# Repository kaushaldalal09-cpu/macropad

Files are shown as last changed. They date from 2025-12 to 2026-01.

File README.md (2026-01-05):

# macropad

This macropad will serve three purposes. One is to increase efficiency for my work by opening my most used apps with the click of a button. The second purpose is for playing video games. And the third feature I want is to have a built in game of tetris using the keys and oled display. My macro pad will include a knob (which will increase/decrease the volume) , a oled screen (to show the volume, or the tetris game depending on what mode I'm in), 12 keys, and RGB lights. 

All silkscreen artwork was created by me

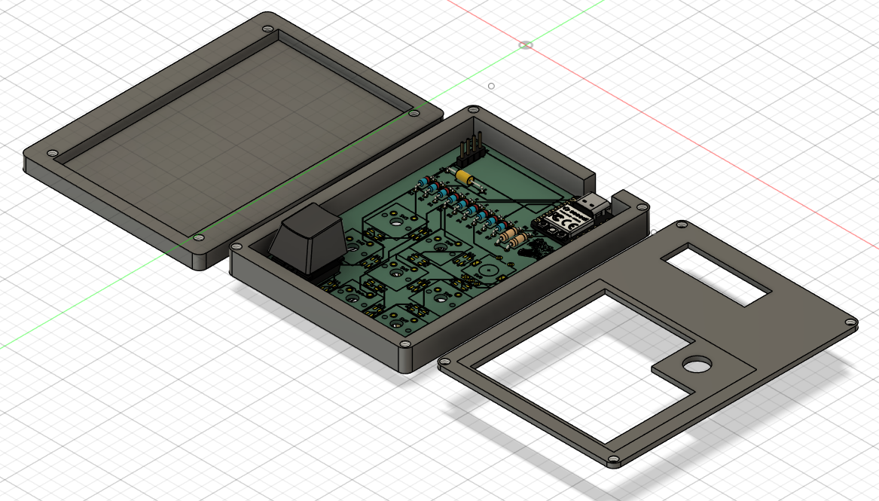
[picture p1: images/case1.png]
Overall hackpad

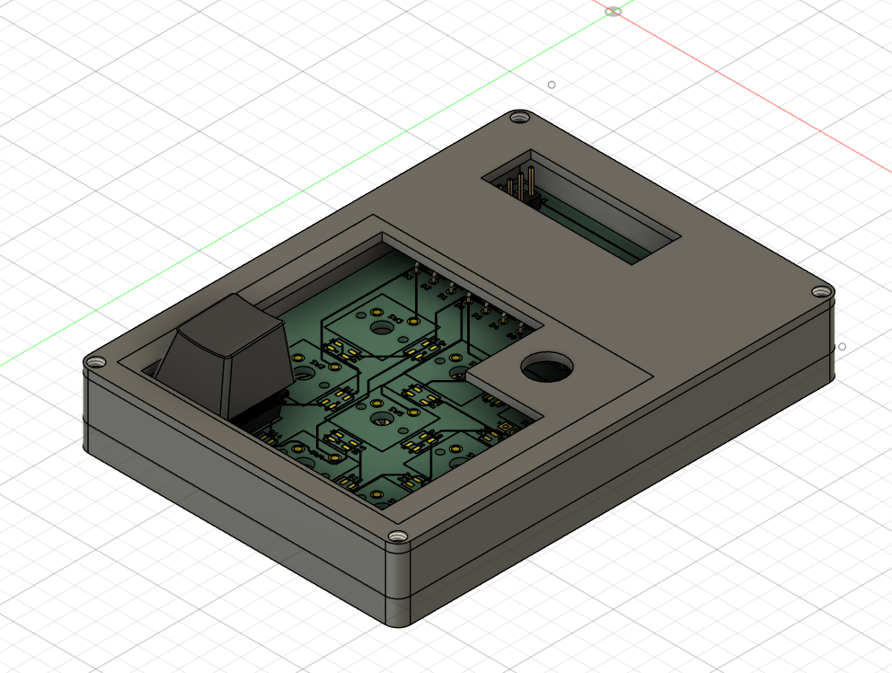
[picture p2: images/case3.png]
Fit together

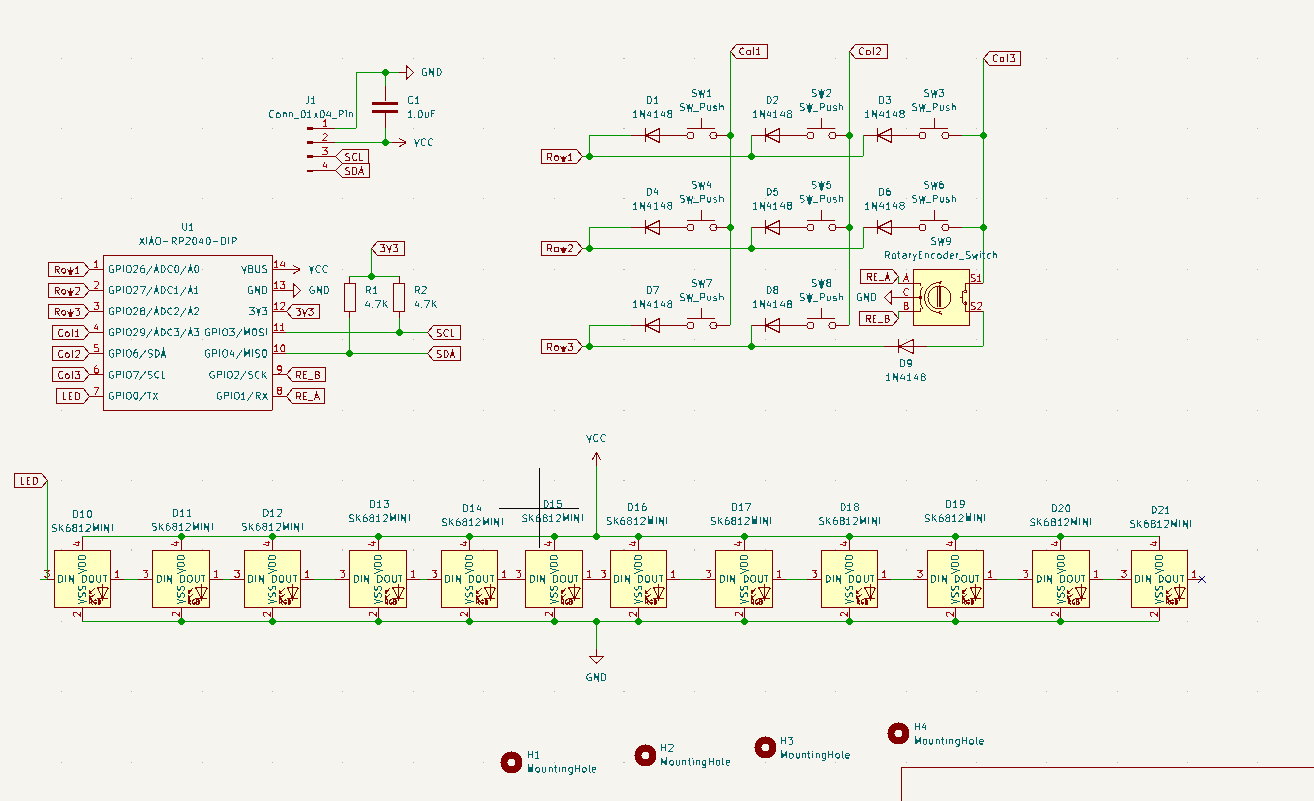
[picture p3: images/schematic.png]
Schematic

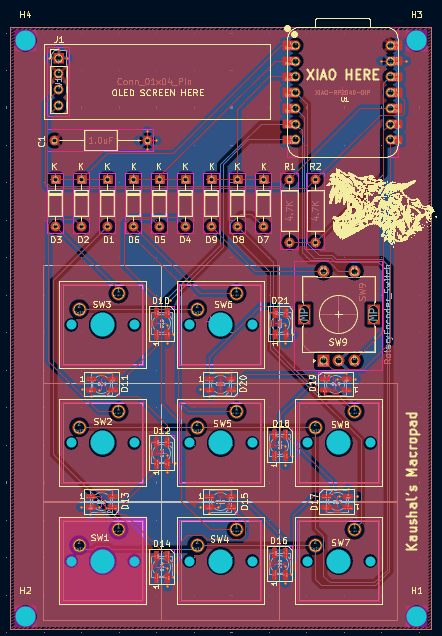
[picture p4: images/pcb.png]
PCB

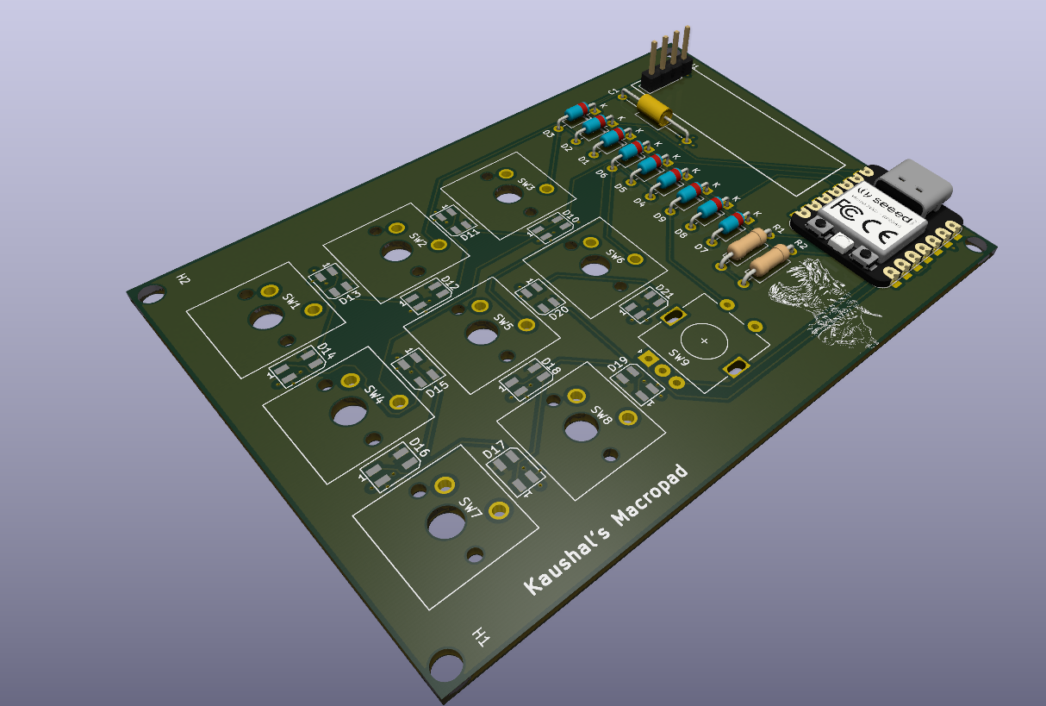
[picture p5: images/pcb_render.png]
PCB Render


BOM:
|Reference |Qty|Value |DNP|Exclude from BOM |Exclude from Board|Footprint |Datasheet |
|---|---|---|---|---|---|---|---|
|C1 |1  |1.0uF | | | |Capacitor_THT:C_Axial_L5.1mm_D3.1mm_P15.00mm_Horizontal |~ |
|D1,D2,D3,D4,D5,D6,D7,D8,D9 |9  |1N4148 | | | |Diode_THT:D_DO-35_SOD27_P7.62mm_Horizontal |https://assets.nexperia.com/documents/data-sheet/1N4148_1N4448.pdf |
|D10,D11,D12,D13,D14,D15,D16,D17,D18,D19,D20,D21|12 |SK6812MINI | | | |LED_SMD:LED_SK6812MINI_PLCC4_3.5x3.5mm_P1.75mm |https://cdn-shop.adafruit.com/product-files/2686/SK6812MINI_REV.01-1-2.pdf|
|H1,H2,H3,H4 |4  |MountingHole | |Excluded from BOM| |MountingHole:MountingHole_3.2mm_M3 |~ |
|J1 |1  |Conn_01x04_Pin | | | |Connector_PinHeader_2.54mm:PinHeader_1x04_P2.54mm_Vertical |~ |
|R1,R2 |2  |4.7K | | | |Resistor_THT:R_Axial_DIN0207_L6.3mm_D2.5mm_P10.16mm_Horizontal|~ |
|SW1,SW2,SW3,SW4,SW5,SW6,SW7,SW8 |8  |SW_Push | | | |Button_Switch_Keyboard:SW_Cherry_MX_1.00u_PCB |~ |
|SW9 |1  |RotaryEncoder_Switch| | | |Rotary_Encoder:RotaryEncoder_Alps_EC11E-Switch_Vertical_H20mm |~ |
|U1 |1  |XIAO-RP2040-DIP | | | |OPL Lib:XIAO-RP2040-DIP | |

Resources used:

https://www.thingiverse.com/thing:6940808

https://github.com/ConstantinoSchillebeeckx/cherry-mx-switch/blob/master/switch.step

https://github.com/ConstantinoSchillebeeckx/cherry-mx-keycaps/blob/master/STEP/Cherry%20MX%20keycaps.step

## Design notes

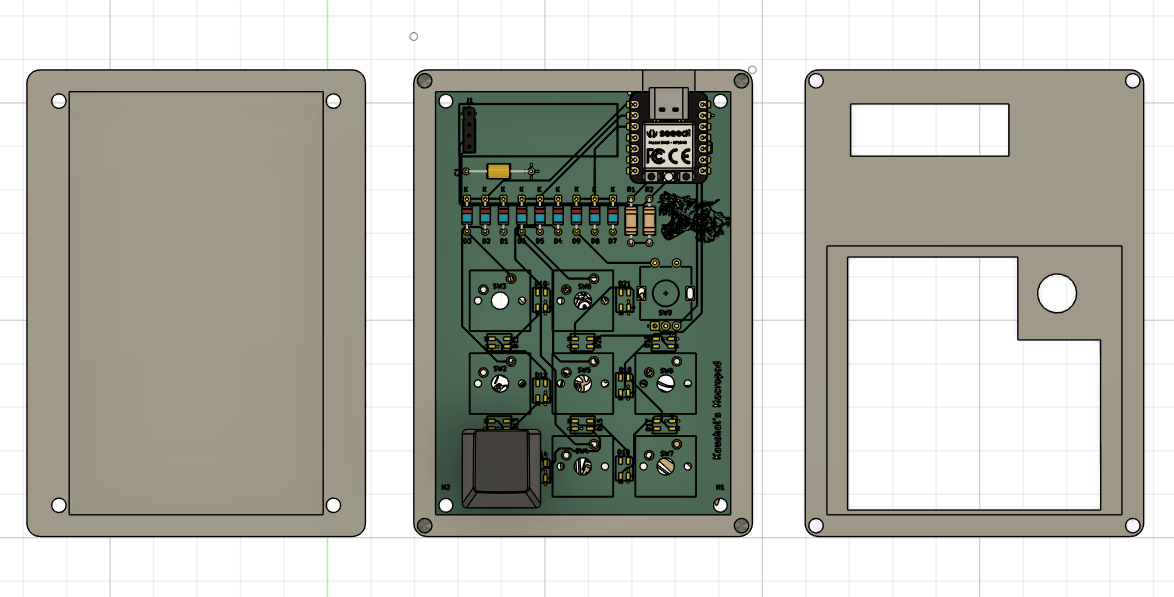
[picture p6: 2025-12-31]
images/case2.png

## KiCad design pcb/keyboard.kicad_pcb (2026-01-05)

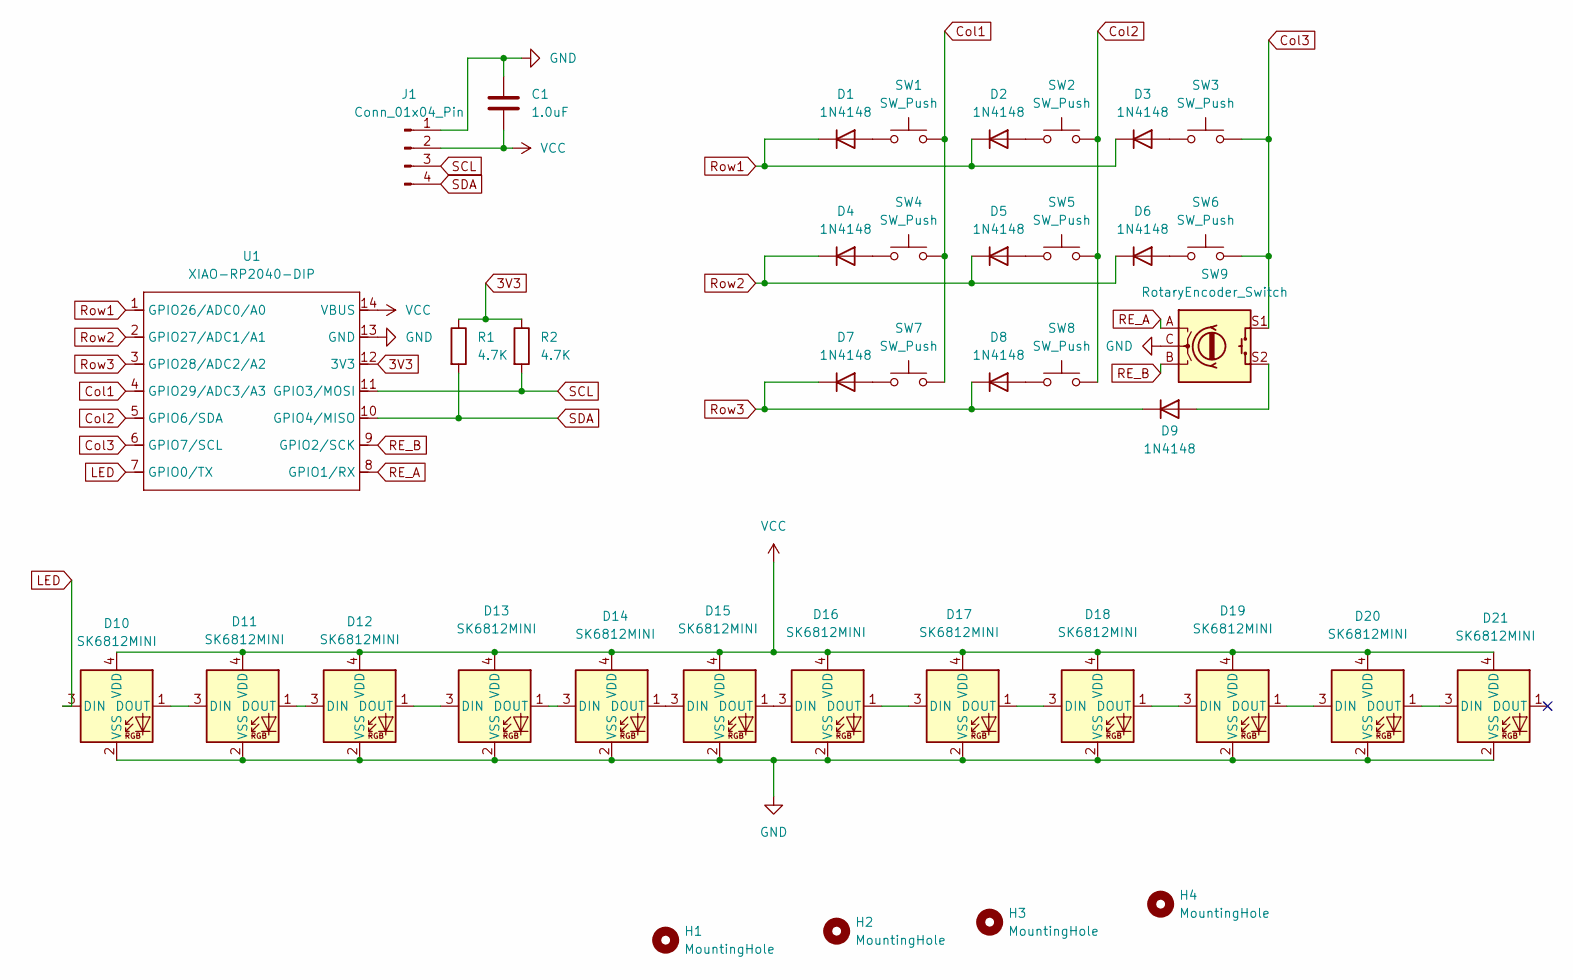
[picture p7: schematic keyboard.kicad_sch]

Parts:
C1: 1.0uF; C_Axial_L5.1mm_D3.1mm_P15.00mm_Horizontal
D1, D2, D3, D4, D5, D6, D7, D8, D9: 1N4148; D_DO-35_SOD27_P7.62mm_Horizontal
D10, D11, D12, D13, D14, D15, D16, D17, D18, D19, D20, D21: SK6812MINI; LED_SK6812MINI_PLCC4_3.5x3.5mm_P1.75mm
H1, H2, H3, H4: MountingHole; MountingHole_3.2mm_M3
J1: Conn_01x04_Pin; PinHeader_1x04_P2.54mm_Vertical
R1, R2: 4.7K; R_Axial_DIN0207_L6.3mm_D2.5mm_P10.16mm_Horizontal
SW1, SW2, SW3, SW4, SW5, SW6, SW7, SW8: SW_Push; SW_Cherry_MX_1.00u_PCB
SW9: RotaryEncoder_Switch; RotaryEncoder_Alps_EC11E-Switch_Vertical_H20mm
U1: XIAO-RP2040-DIP

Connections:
3V3: R1.1, R2.1, U1.12 (3V3)
Col1: SW1.2, SW4.2, SW7.2, U1.4 (GPIO29/ADC3/A3)
Col2: SW2.2, SW5.2, SW8.2, U1.5 (GPIO6/SDA)
Col3: SW3.2, SW6.2, SW9.S1, U1.6 (GPIO7/SCL)
GND: C1.1, D10.2 (VSS), D11.2 (VSS), D12.2 (VSS), D13.2 (VSS), D14.2 (VSS), D15.2 (VSS), D16.2 (VSS), D17.2 (VSS), D18.2 (VSS), D19.2 (VSS), D20.2 (VSS), D21.2 (VSS), J1.1, SW9.C, U1.13 (GND)
LED: D10.3 (DIN), U1.7 (GPIO0/TX)
unnamed: D1.2 (A), SW1.1
unnamed: D2.2 (A), SW2.1
unnamed: D3.2 (A), SW3.1
unnamed: D4.2 (A), SW4.1
unnamed: D5.2 (A), SW5.1
unnamed: D6.2 (A), SW6.1
unnamed: D7.2 (A), SW7.1
unnamed: D8.2 (A), SW8.1
unnamed: D9.2 (A), SW9.S2
unnamed: D10.1 (DOUT), D11.3 (DIN)
unnamed: D11.1 (DOUT), D12.3 (DIN)
unnamed: D12.1 (DOUT), D13.3 (DIN)
unnamed: D13.1 (DOUT), D14.3 (DIN)
unnamed: D14.1 (DOUT), D15.3 (DIN)
unnamed: D15.1 (DOUT), D16.3 (DIN)
unnamed: D16.1 (DOUT), D17.3 (DIN)
unnamed: D17.1 (DOUT), D18.3 (DIN)
unnamed: D18.1 (DOUT), D19.3 (DIN)
unnamed: D19.1 (DOUT), D20.3 (DIN)
unnamed: D20.1 (DOUT), D21.3 (DIN)
RE_A: SW9.A, U1.8 (GPIO1/RX)
RE_B: SW9.B, U1.9 (GPIO2/SCK)
Row1: D1.1 (K), D2.1 (K), D3.1 (K), U1.1 (GPIO26/ADC0/A0)
Row2: D4.1 (K), D5.1 (K), D6.1 (K), U1.2 (GPIO27/ADC1/A1)
Row3: D7.1 (K), D8.1 (K), D9.1 (K), U1.3 (GPIO28/ADC2/A2)
SCL: J1.3, R2.2, U1.11 (GPIO3/MOSI)
SDA: J1.4, R1.2, U1.10 (GPIO4/MISO)
VCC: C1.2, D10.4 (VDD), D11.4 (VDD), D12.4 (VDD), D13.4 (VDD), D14.4 (VDD), D15.4 (VDD), D16.4 (VDD), D17.4 (VDD), D18.4 (VDD), D19.4 (VDD), D20.4 (VDD), D21.4 (VDD), J1.2, U1.14 (VBUS)

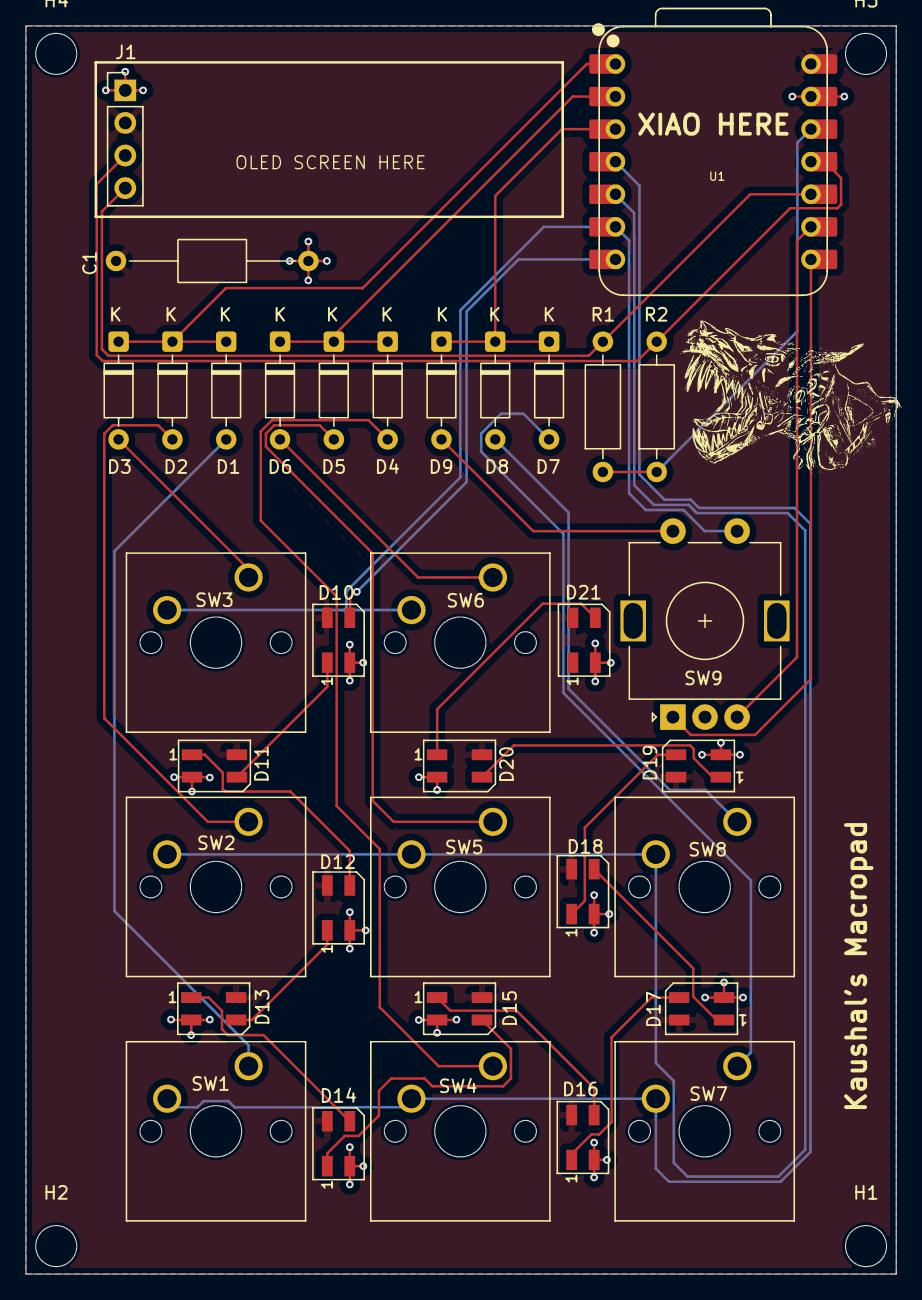
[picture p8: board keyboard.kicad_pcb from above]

Board: 2 copper layers, 67.9 x 97.3 mm, 39 parts (0 on the bottom side), 34 nets.

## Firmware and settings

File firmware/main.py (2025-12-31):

import board
import busio
import displayio
import terminalio
import random
import time
import adafruit_displayio_ssd1306
from adafruit_display_text import label
from kmk.kmk_keyboard import KMKKeyboard
from kmk.keys import KC
from kmk.scanners import DiodeOrientation
from kmk.modules.layers import Layers
from kmk.modules.encoder import EncoderHandler
from kmk.extensions.RGB import RGB

keyboard = KMKKeyboard()

# --- Hardware Configuration ---
keyboard.col_pins = (board.GP29, board.GP6, board.GP7)
keyboard.row_pins = (board.GP26, board.GP27, board.GP28)
keyboard.diode_orientation = DiodeOrientation.COL2ROW

# RGB Setup on GPIO0 (Pin 7)
rgb = RGB(pixel_pin=board.GP0, num_pixels=1, val_limit=255, hue_default=0)
keyboard.extensions.append(rgb)

# Encoder and Layer Modules
layers = Layers()
encoder_handler = EncoderHandler()
keyboard.modules = [layers, encoder_handler]
encoder_handler.pins = ((board.GP1, board.GP2, None, False),)

# OLED Initialization (SCL: GP3, SDA: GP4)
displayio.release_displays()
i2c = busio.I2C(scl=board.GP3, sda=board.GP4)
display_bus = displayio.I2CDisplay(i2c, device_address=0x3C)
display = adafruit_displayio_ssd1306.SSD1306(display_bus, width=128, height=32)

# --- Tetris Engine Constants ---
BOARD_W = 10
BOARD_H = 8
SHAPES = [
    [[1, 1, 1, 1]], # I
    [[1, 1], [1, 1]], # O
    [[0, 1, 0], [1, 1, 1]], # T
    [[0, 1, 1], [1, 1, 0]], # S
    [[1, 1, 0], [0, 1, 1]], # Z
    [[1, 0, 0], [1, 1, 1]], # L
    [[0, 0, 1], [1, 1, 1]]  # J
]

class TetrisGame:
    def __init__(self):
        self.reset()

    def reset(self):
        self.board = [[0] * BOARD_W for _ in range(BOARD_H)]
        self.new_piece()
        self.score = 0
        self.game_over = False

    def new_piece(self):
        self.piece = random.choice(SHAPES)
        self.px = BOARD_W // 2 - len(self.piece[0]) // 2
        self.py = 0
        if self.check_collision(self.px, self.py):
            self.game_over = True

    def check_collision(self, x, y, piece=None):
        piece = piece or self.piece
        for r, row in enumerate(piece):
            for c, val in enumerate(row):
                if val:
                    if (x + c < 0 or x + c >= BOARD_W or 
                        y + r >= BOARD_H or self.board[y + r][x + c]):
                        return True
        return False

    def rotate(self):
        new_p = [list(r) for r in zip(*self.piece[::-1])]
        if not self.check_collision(self.px, self.py, new_p):
            self.piece = new_p

    def move(self, dx, dy):
        if not self.check_collision(self.px + dx, self.py + dy):
            self.px += dx
            self.py += dy
            return True
        if dy > 0:
            self.lock_piece()
        return False

    def lock_piece(self):
        for r, row in enumerate(self.piece):
            for c, val in enumerate(row):
                if val: self.board[self.py + r][self.px + c] = 1
        self.clear_lines()
        self.new_piece()

    def clear_lines(self):
        self.board = [row for row in self.board if not all(row)]
        while len(self.board) < BOARD_H:
            self.board.insert(0, [0] * BOARD_W)
            self.score += 10

    def draw(self):
        bitmap = displayio.Bitmap(128, 32, 2)
        palette = displayio.Palette(2)
        palette[0], palette[1] = 0x000000, 0xFFFFFF
        for r in range(BOARD_H):
            for c in range(BOARD_W):
                if self.board[r][c]: self._fill_rect(bitmap, c*4 + 44, r*4, 3, 3)
        for r, row in enumerate(self.piece):
            for c, val in enumerate(row):
                if val: self._fill_rect(bitmap, (self.px+c)*4 + 44, (self.py+r)*4, 3, 3)
        tg = displayio.Group()
        tg.append(displayio.TileGrid(bitmap, pixel_shader=palette))
        display.show(tg)

    def _fill_rect(self, bitmap, x, y, w, h):
        for i in range(x, x+w):
            for j in range(y, y+h):
                if 0 <= i < 128 and 0 <= j < 32: bitmap[i, j] = 1

tetris = TetrisGame()

# --- Keymap ---
# SW9 (Index 8) is set to KC.RGB_HUI to cycle colors on every layer
keyboard.keymap = [
    [KC.LCTL(KC.C), KC.LCTL(KC.V), KC.LCTL(KC.Z), KC.F1, KC.F2, KC.F3, KC.F4, KC.F5, KC.RGB_HUI],
    [KC.W, KC.A, KC.S, KC.D, KC.Q, KC.E, KC.R, KC.F, KC.RGB_HUI],
    [KC.NO, KC.TRNS, KC.NO, KC.TRNS, KC.TRNS, KC.TRNS, KC.NO, KC.TRNS, KC.RGB_HUI]
]

# --- Mode Logic ---
current_mode = 0
def update_mode(direction):
    global current_mode
    current_mode = (current_mode + (1 if direction > 0 else -1)) % 3
    layers.activate(current_mode)
    splash = displayio.Group()
    modes = ["WORK", "GAME", "TETRIS"]
    splash.append(label.Label(terminalio.FONT, text=f"MODE: {modes[current_mode]}", x=30, y=15))
    display.show(splash)
    if current_mode == 2: tetris.reset()

encoder_handler.set_callback(lambda dir: update_mode(dir))

# --- Custom Runtime Loop ---
last_gravity = time.monotonic()
def main_loop_hook():
    global last_gravity
    if current_mode != 2: return
    if tetris.game_over: tetris.reset()
    
    # Manual matrix check for Tetris inputs
    keys = keyboard.matrix.update()
    if keys:
        for key in keys:
            if key.pressed:
                if key.number == 1: tetris.rotate()
                if key.number == 3: tetris.move(-1, 0)
                if key.number == 4: tetris.move(0, 1)
                if key.number == 5: tetris.move(1, 0)
                if key.number == 7: 
                    while tetris.move(0, 1): pass

    if time.monotonic() - last_gravity > 0.8:
        tetris.move(0, 1)
        last_gravity = time.monotonic()
        tetris.draw()

keyboard.after_matrix_scan = main_loop_hook

if __name__ == '__main__':
    keyboard.go()

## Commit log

2025-12-31 added design files
    [keyboard-B_Cu.gbr, keyboard-B_Mask.gbr, keyboard-B_Paste.gbr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]
2026-01-05 new pcb image
    [keyboard.kicad_pcb]
